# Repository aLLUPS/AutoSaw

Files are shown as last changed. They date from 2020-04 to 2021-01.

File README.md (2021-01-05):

# AutoSaw
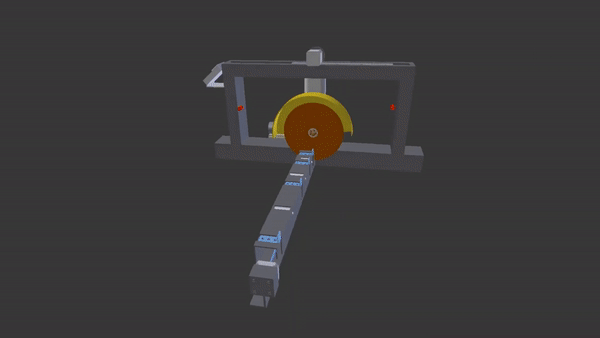
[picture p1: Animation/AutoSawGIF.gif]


This repository contains the information about ATMEGA 32A micro-controller based project - The Automated Abrasive Saw - 'AutoSaw'.
* It is a machine which cuts long metal box bars into smaller pieces automatically, after the user enter the input length and number of pieces required.
* This repository consists:
    1. 3dModel:- The 3d model of the machine. (.FCSTD file & .stl file)
    2. Animation:- The animation about the operation of the machine.
    3. AtmelProject:- micro-C codes to program the whole machine.
    4. PCB:- The Printed circuit board design, the wiring of Electronic/Electric components with PCB.

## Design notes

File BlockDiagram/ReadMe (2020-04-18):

* This folder contains the png image of the block diagram of the machine. 
* There are 04 input sensors(Limit switch, two IR sensors and Wheel Encoder/Photo-electric encoder)
* There are 05 motors (Stepper motor, two DC gear motors, high RPM DC motor, servo motor) are the main outputs of the machine.
* There is a 20*4 character LCD display and push buttons set as user interface.

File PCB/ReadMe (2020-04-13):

This folder contains:
  * RealWorldImplementation:- The JPEG images of real world implementation.
  * PCB_Design :-The EAGLE project (The EAGLE .sch and .brd files of the PCB).

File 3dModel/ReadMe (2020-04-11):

* This folder contains the .FCStd file and the .stl files of the machine.
* The .FCStd file can be opened using 'FreeCad software' and .stl file can be viewed using 3d viewer of paint 3d.

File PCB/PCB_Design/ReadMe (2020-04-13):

* This folder contains the eagle project and images of the pcb design
* You can open the .sch and .brd files using Audodesk EAGLE software.

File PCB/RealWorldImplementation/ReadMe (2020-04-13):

This folder contains some images of the PCB in the real world implementation

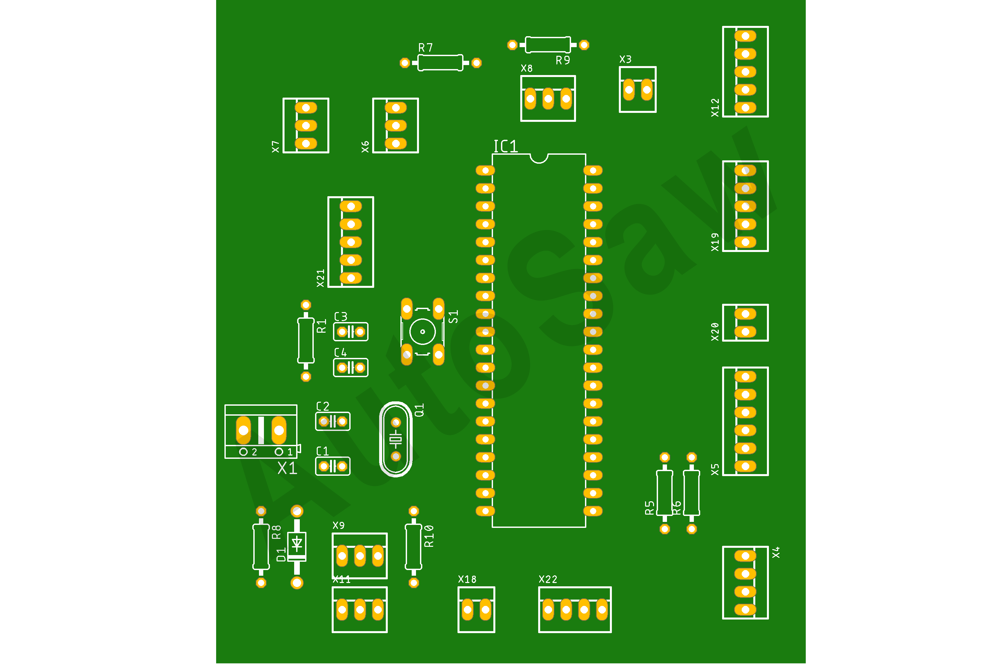
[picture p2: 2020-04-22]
PCB/PCB_Design/Top_side_PCB.png

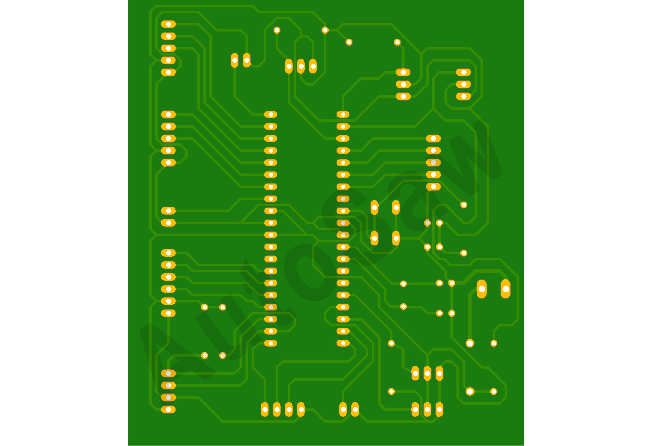
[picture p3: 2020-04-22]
PCB/PCB_Design/Bottom_side_PCB.png

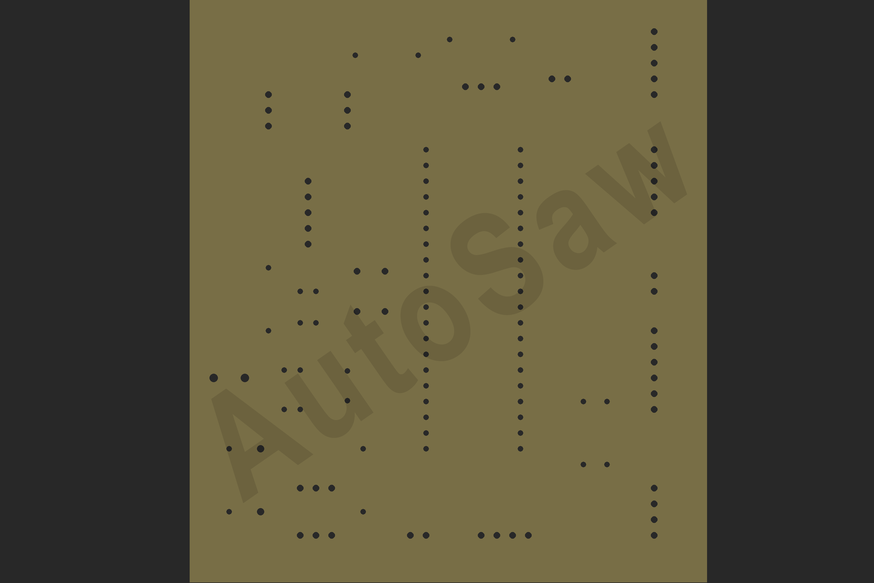
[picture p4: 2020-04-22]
PCB/PCB_Design/Drills_PCB.png

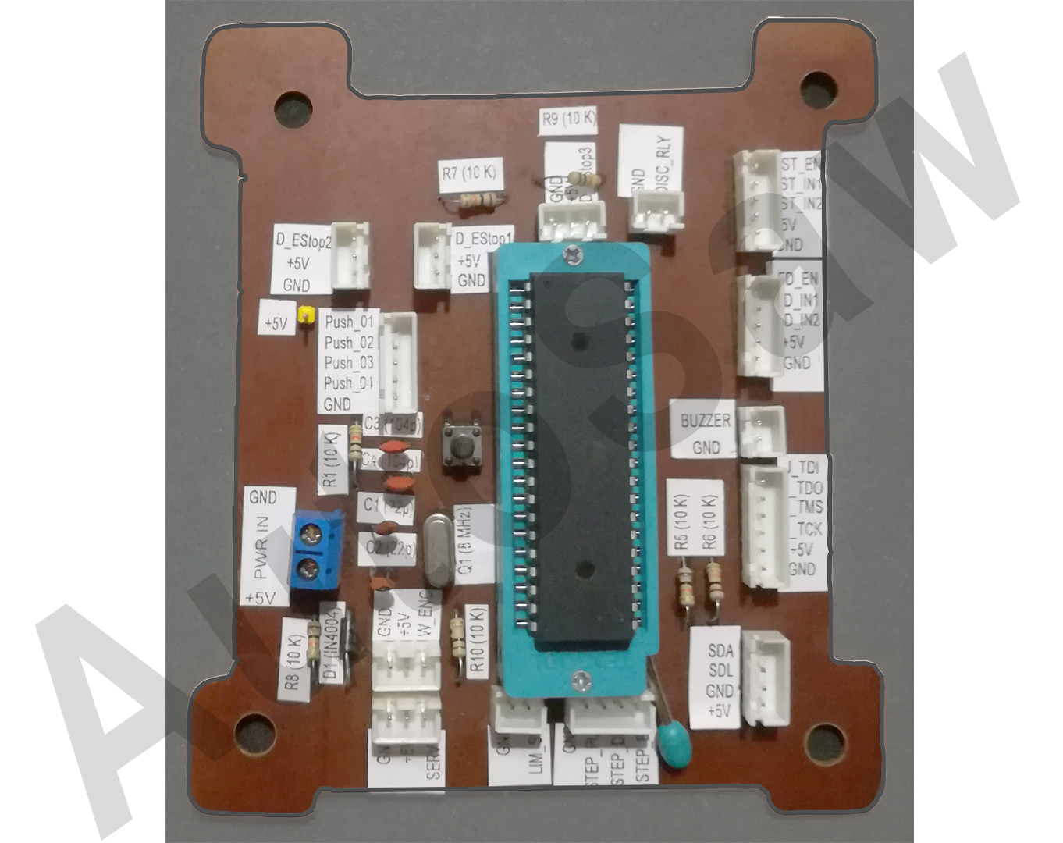
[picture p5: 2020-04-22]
PCB/RealWorldImplementation/03 Componets_attached.png

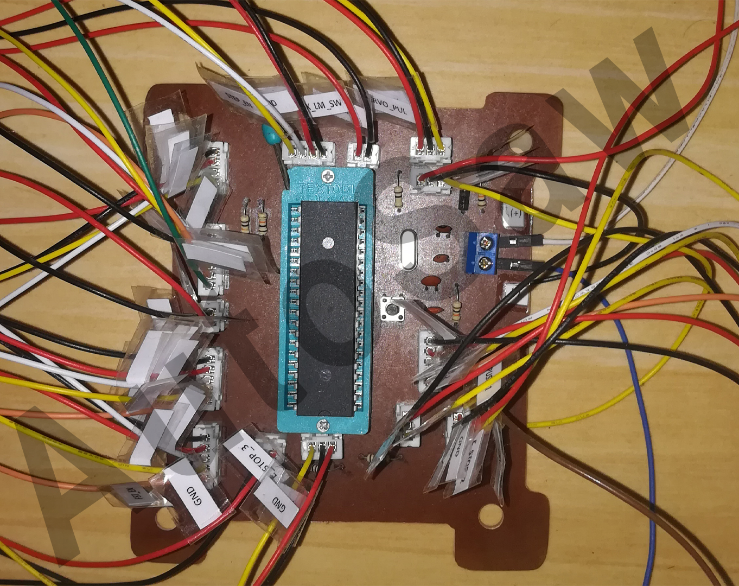
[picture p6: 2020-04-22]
PCB/RealWorldImplementation/04 Wires_attached.png

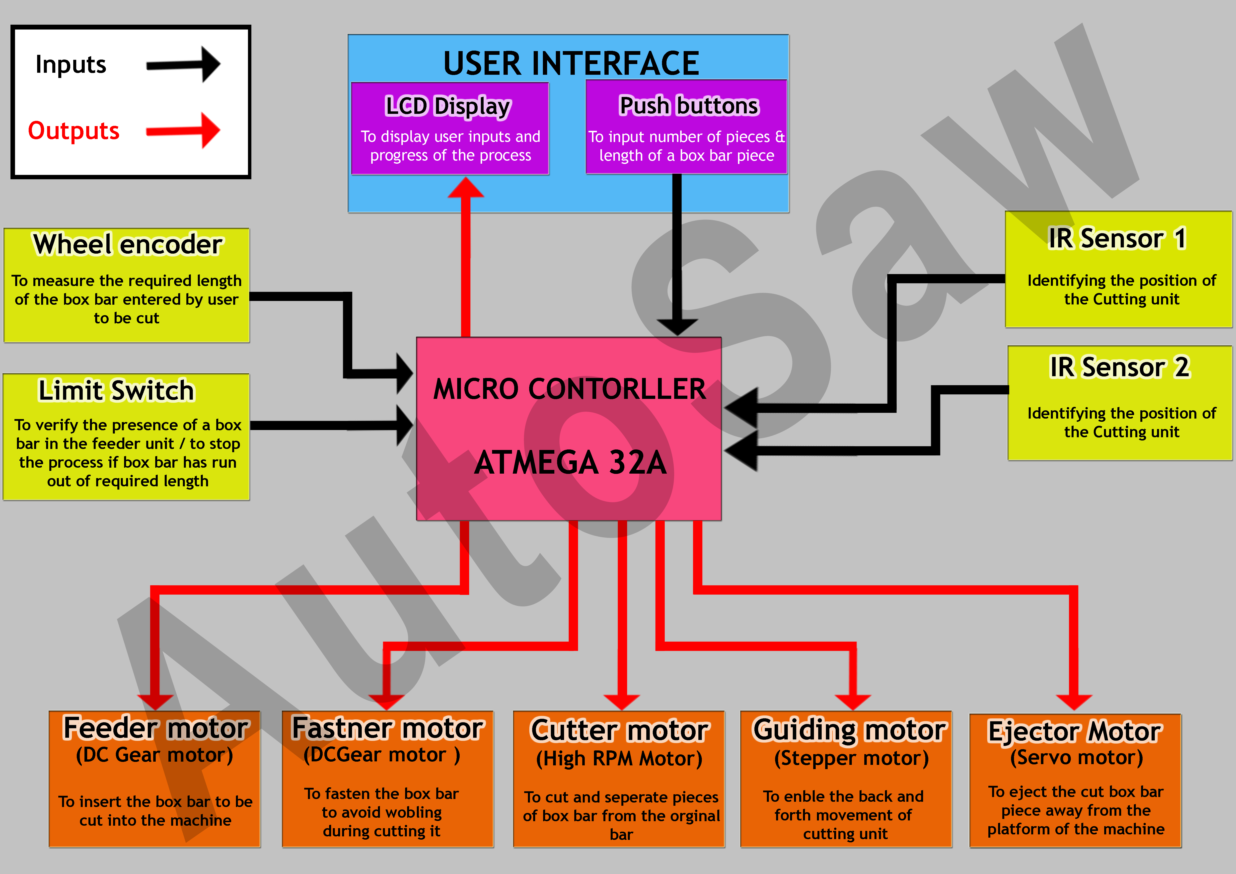
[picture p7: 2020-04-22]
BlockDiagram/Block_Diagram.png

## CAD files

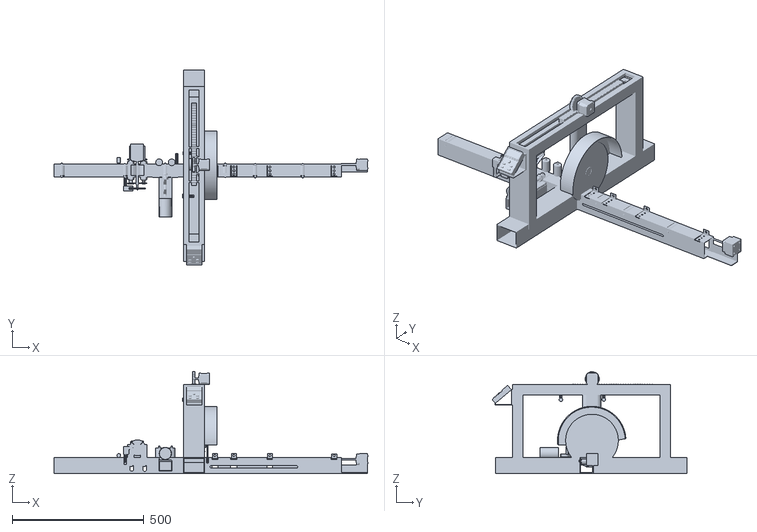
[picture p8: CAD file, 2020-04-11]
3dModel/STL_file.stl
1192.6 x 740.0 x 388.3

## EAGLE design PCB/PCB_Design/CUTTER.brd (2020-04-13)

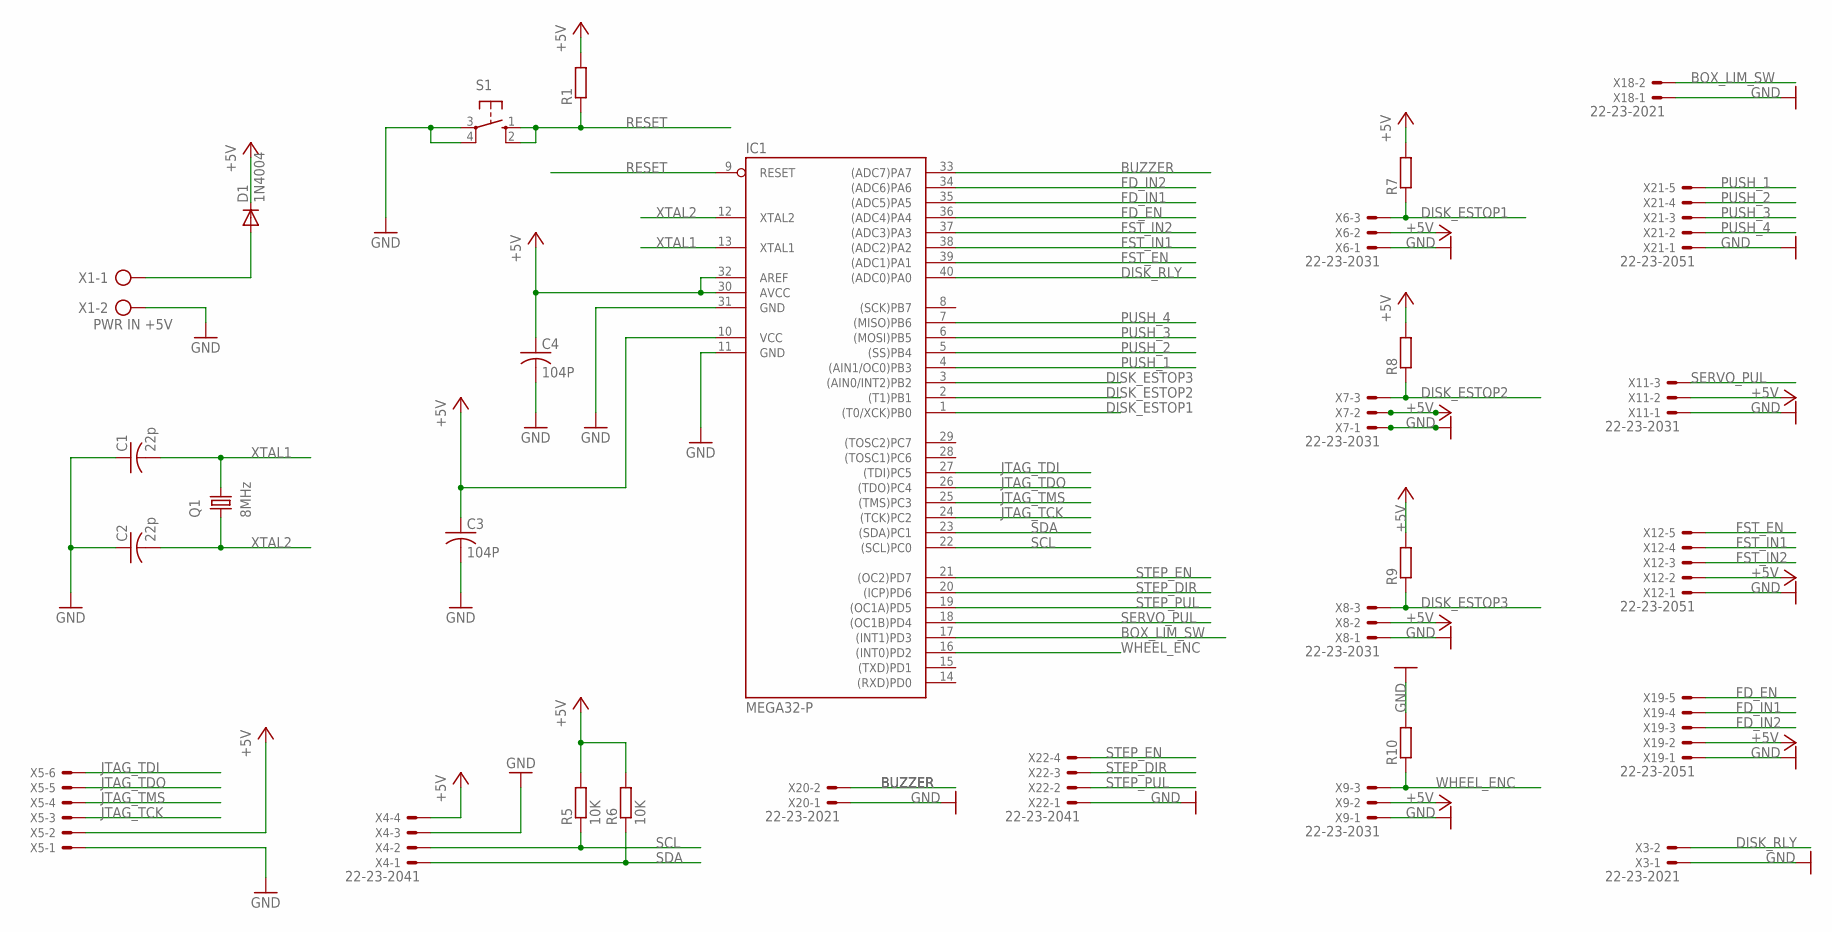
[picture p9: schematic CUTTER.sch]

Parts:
C1, C2: 22p; C025-025X050
C3, C4: 104P; C025-025X050
D1: 1N4004; DO41-10
IC1: MEGA32-P; DIL40
Q1: 8MHz; HC49/S
R1, R7, R8, R9, R10: R-EU_0207/10; 0207/10
R5, R6: 10K; 0207/10
S1: 10-XX; B3F-10XX
X1: PWR IN +5V; AK500/2
X3, X18, X20: 22-23-2021
X4, X22: 22-23-2041
X5: 22-23-2061
X6, X7, X8, X9, X11: 22-23-2031
X12, X19, X21: 22-23-2051

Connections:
+5V: C3.1, C4.1, D1.C, IC1.10 (VCC), IC1.30 (AVCC), IC1.32 (AREF), R1.2, R5.2, R6.2, R7.2, R8.2, R9.2, X4.4, X5.2, X6.2, X7.2, X8.2, X9.2, X11.2, X12.2, X19.2
BOX_LIM_SW: IC1.17 ((INT1)PD3), X18.2
BUZZER: IC1.33 ((ADC7)PA7), X20.2
DISK_ESTOP1: IC1.1 ((T0/XCK)PB0), R7.1, X6.3
DISK_ESTOP2: IC1.2 ((T1)PB1), R8.1, X7.3
DISK_ESTOP3: IC1.3 ((AIN0/INT2)PB2), R9.1, X8.3
DISK_RLY: IC1.40 ((ADC0)PA0), X3.2
FD_EN: IC1.36 ((ADC4)PA4), X19.5
FD_IN1: IC1.35 ((ADC5)PA5), X19.4
FD_IN2: IC1.34 ((ADC6)PA6), X19.3
FST_EN: IC1.39 ((ADC1)PA1), X12.5
FST_IN1: IC1.38 ((ADC2)PA2), X12.4
FST_IN2: IC1.37 ((ADC3)PA3), X12.3
GND: C1.1, C2.1, C3.2, C4.2, IC1.11 (GND), IC1.31 (GND), R10.2, S1.3, S1.4 (P1), X1.2, X3.1, X4.3, X5.1, X6.1, X7.1, X8.1, X9.1, X11.1, X12.1, X18.1, X19.1, X20.1, X21.1, X22.1
JTAG_TCK: IC1.24 ((TCK)PC2), X5.3
JTAG_TDI: IC1.27 ((TDI)PC5), X5.6
JTAG_TDO: IC1.26 ((TDO)PC4), X5.5
JTAG_TMS: IC1.25 ((TMS)PC3), X5.4
unnamed: D1.A, X1.1
PUSH_1: IC1.4 ((AIN1/OC0)PB3), X21.5
PUSH_2: IC1.5 ((SS)PB4), X21.4
PUSH_3: IC1.6 ((MOSI)PB5), X21.3
PUSH_4: IC1.7 ((MISO)PB6), X21.2
RESET: IC1.9 (RESET), R1.1, S1.1 (S), S1.2 (S1)
SCL: IC1.22 ((SCL)PC0), R5.1, X4.2
SDA: IC1.23 ((SDA)PC1), R6.1, X4.1
SERVO_PUL: IC1.18 ((OC1B)PD4), X11.3
STEP_DIR: IC1.20 ((ICP)PD6), X22.3
STEP_EN: IC1.21 ((OC2)PD7), X22.4
STEP_PUL: IC1.19 ((OC1A)PD5), X22.2
WHEEL_ENC: IC1.16 ((INT0)PD2), R10.1, X9.3
XTAL1: C1.2, IC1.13 (XTAL1), Q1.2
XTAL2: C2.2, IC1.12 (XTAL2), Q1.1

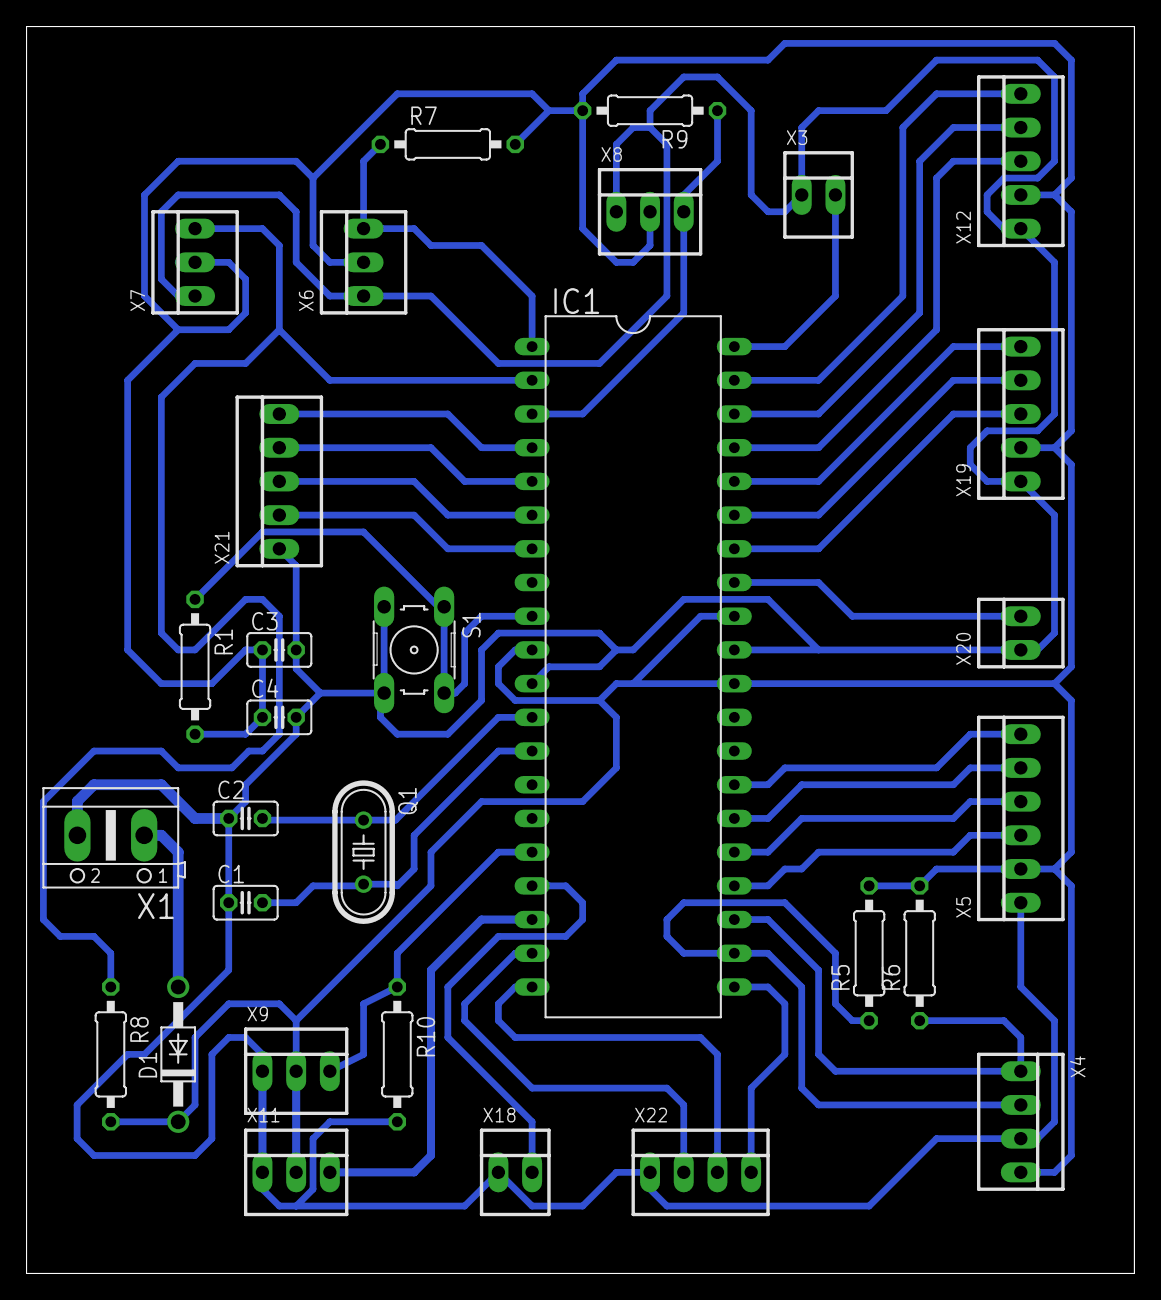
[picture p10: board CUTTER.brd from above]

Board: 2 copper layers, 83.5 x 94.0 mm, 30 parts (0 on the bottom side), 33 nets.
